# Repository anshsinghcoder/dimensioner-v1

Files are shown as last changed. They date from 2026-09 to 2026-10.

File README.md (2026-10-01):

# dimensioner v1 
MAAP 1 is a automated DIM system that costs 10 times less compared to the current options . 
it is aluminum blasted but u can completely use fibre 3d printing for this . i have removed the wieging scale from research that most users dont need it. 

Overview:
MAAP-1 Utilizes a custom ESP32-based PCB, 3 LiDAR sensors to  instantly calculate the length ,  height and width of any parcel .
Designed for logistics, warehouses . i have included electronics components make sure u add it in your cad library. sorry though not much room for customisation many pins are used , feel free to play around with the scematics if u wish
- it also features a camera system which snaps images along side the dim . how ever please make sure the camera module u use comes with a sd slot or just add a pin. 

Hardware Architecture
1. Custom PCB (KiCad)
The brains of the operation is a custom PCB designed to be attached anywhere in the frame it has a 2 hole enclosure that is also included .

Microcontroller: ESP32-WROOM
Power: 5V input, regulated to 3.3V via AMS1117 for logic.

2. Mechanical Structure
  - T-slot aluminum extrusion holding the overhead LiDAR .
  - Dual forward-facing structural arms housing inward-facing LiDARs 
  - control box housing the custom PCB, screen, buttons, and thermal printer.

Repository Structure

MAAP-1:
- Firmware             # PLEASE CALIBRATE AS PER NEEDS 
- Hardware            # KiCad PCB design files, Schematics, and Gerbers
- Mechanical           # 3D files for the enclosure and arms PLEASE ADD THE PCB ENCLOSURE AND SCREEN WHERE YOU NEED .
- README.md             # Project documentation

Here is the complete Bill of Materials (BOM) to build your own.
IF U WANT AMOUNTS IN DOLLARS PLEASE REFER TO BOM.CSV 

| Component | Qty | Est. Price | Link / Source |
| --- | --- | --- | --- |
| **ESP32 WROOM-32 Dev Board** | 1 | ₹1850 | [Robu.in](https://robu.in/product/nodemcu-esp-32s-esp-32e-wifi-serial-wifi-bluetooth/?utm_source=gemini) |
| **ESP32-CAM Module** | 1 | ₹2499 | [Robu.in](https://robu.in/product/esp32-cam-wifi-module-bluetooth-with-ov2640-camera-module-2mp/?utm_source=gemini) |
| **VL53L0X ToF LiDAR Sensor** | 3 | ₹4500 *(₹1499 each)* | [Robu.in](https://www.google.com/search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) |
| **1.3" I2C OLED Display (White)** | 1 | ₹299 | [Robu.in](https://robu.in/product/1-3-inch-i2c-oled-display-module-4-pin-white/?utm_source=gemini) |
| **Mechanical Switch / Arcade Button** | 1 | ₹150 | Local Electronics Market |
| **5V 3A Power Adapter** | 1 | ₹250 | Local Electronics Market |
| **LED Strip / Ring Light (6000K)** | 1 | ₹150 | Local Electronics Market |
| **Aluminum 2020 V-Slot Extrusions** | 2m | ₹1000 | Local Hardware Supplier |
| **Clear Polycarbonate/Acrylic Sheets** | 1 | ₹900 | Local Laser-Cutting Shop |
| **Custom PCB (Matte Black + ENIG)** | 5 | ₹1850 | [JLCPCB](https://jlcpcb.com?utm_source=gemini) |
| **Hardware Kit (T-Nuts, M4 Bolts, Brackets)** | 1 | ₹350 | Local Hardware Supplier |



* **Total Estimated Build Cost:** **~₹23,500 (approx. $235 USD)**

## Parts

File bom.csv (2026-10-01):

W | PARTS | qty | PRICE | LINKS
 | ESP32 WROOM-32 Dev Board | 1 | 20$ | [Robu.in](https://robu.in/product/nodemcu-esp-32s-esp-32e-wifi-serial-wifi-bluetooth/?utm_source=gemini)
 | ESP32-CAM Module | 1 | 26$ | [Robu.in](https://robu.in/product/esp32-cam-wifi-module-bluetooth-with-ov2640-camera-module-2mp/
 | VL53L0X ToF LiDAR Sensor | 3 | 45$ (15$ EACH) | [Robu.in](https://www.google.com/search
 | I2C OLED Display (White) | 1 | 4$ | Robu.in](https://robu.in/product/1-3-inch-i2c-oled-display-module-4-pin-white/?utm_source=gemini)
 | Mechanical Switch / Arcade Button | 1 | 3$ | https://techtonics.in/product/tactile-push-button-switch-4-pin-6x6x5-pack-of-10/
 | 5V 3A Power Adapter | 1 | 5$ | Local Electronics Market
 | LED Strip / Ring Light (6000K) | 1 | $4 | Local Electronics Market
 | Aluminum 2020 V-Slot Extrusions | 2m | 20$ | Local Hardware Supplier
 | Clear Polycarbonate/Acrylic Sheets | 1 | 10$ | Local Laser-Cutting Shop
 | Custom PCB | 5 | 25$ | [JLCPCB]
 | Hardware Kit (T-Nuts, M4 Bolts, Brackets) | 1 | 4$ | Local Hardware Supplier

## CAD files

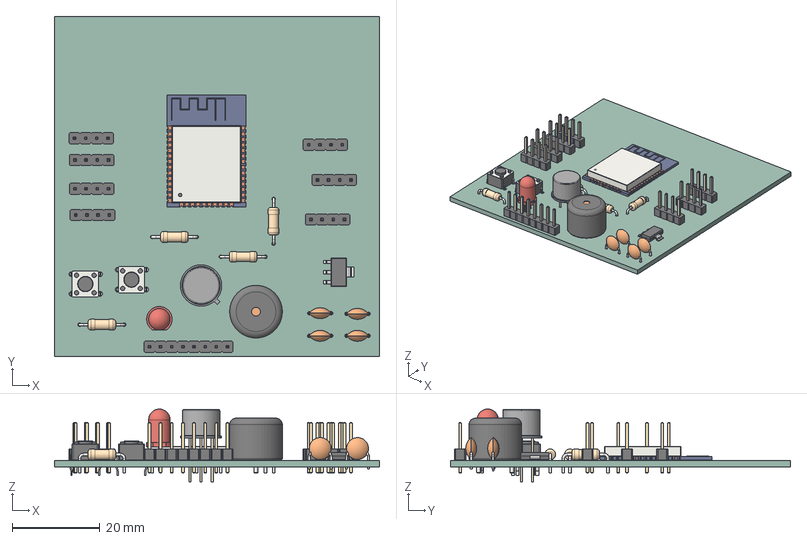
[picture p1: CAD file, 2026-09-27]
hardware/MAAP-1.step
74.0 x 77.5 x 16.6 mm
C_Disc_D50mm_W25mm_P500mm x 4
PinHeader_1x04_P254mm_Vertical x 7
ESP32-WROOM-32
SW_PUSH_6mm x 2
LED_D5.0mm
PinHeader_1x08_P254mm_Vertical
Buzzer_12x95RM76
SOT-223
R_Axial_DIN0207_L63mm_D25mm_P1016mm_Horizontal x 4
TO-39-3
MAA78BE_PCB

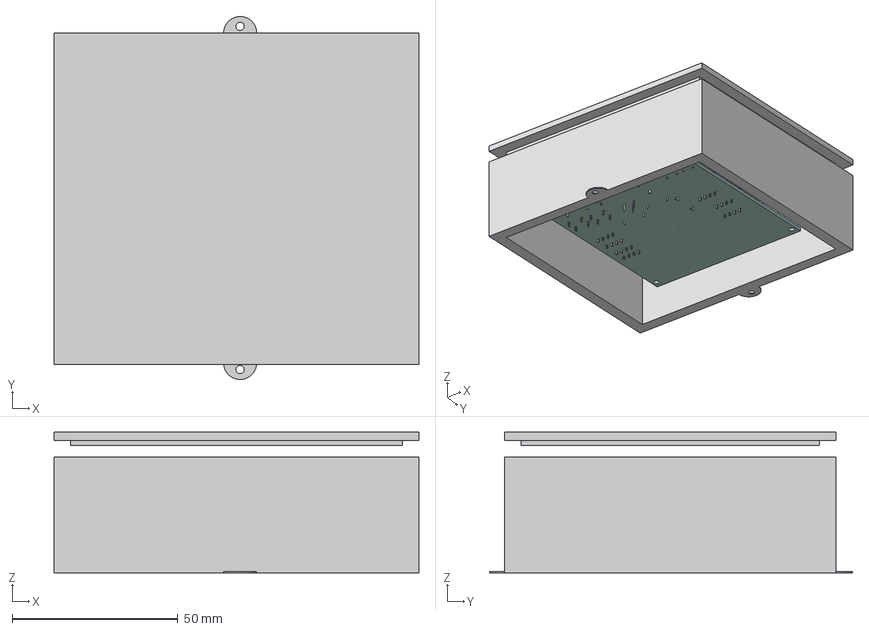
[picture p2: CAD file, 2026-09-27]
mechanical/pcb mounting enclosure.step
110.0 x 109.5 x 42.5 mm

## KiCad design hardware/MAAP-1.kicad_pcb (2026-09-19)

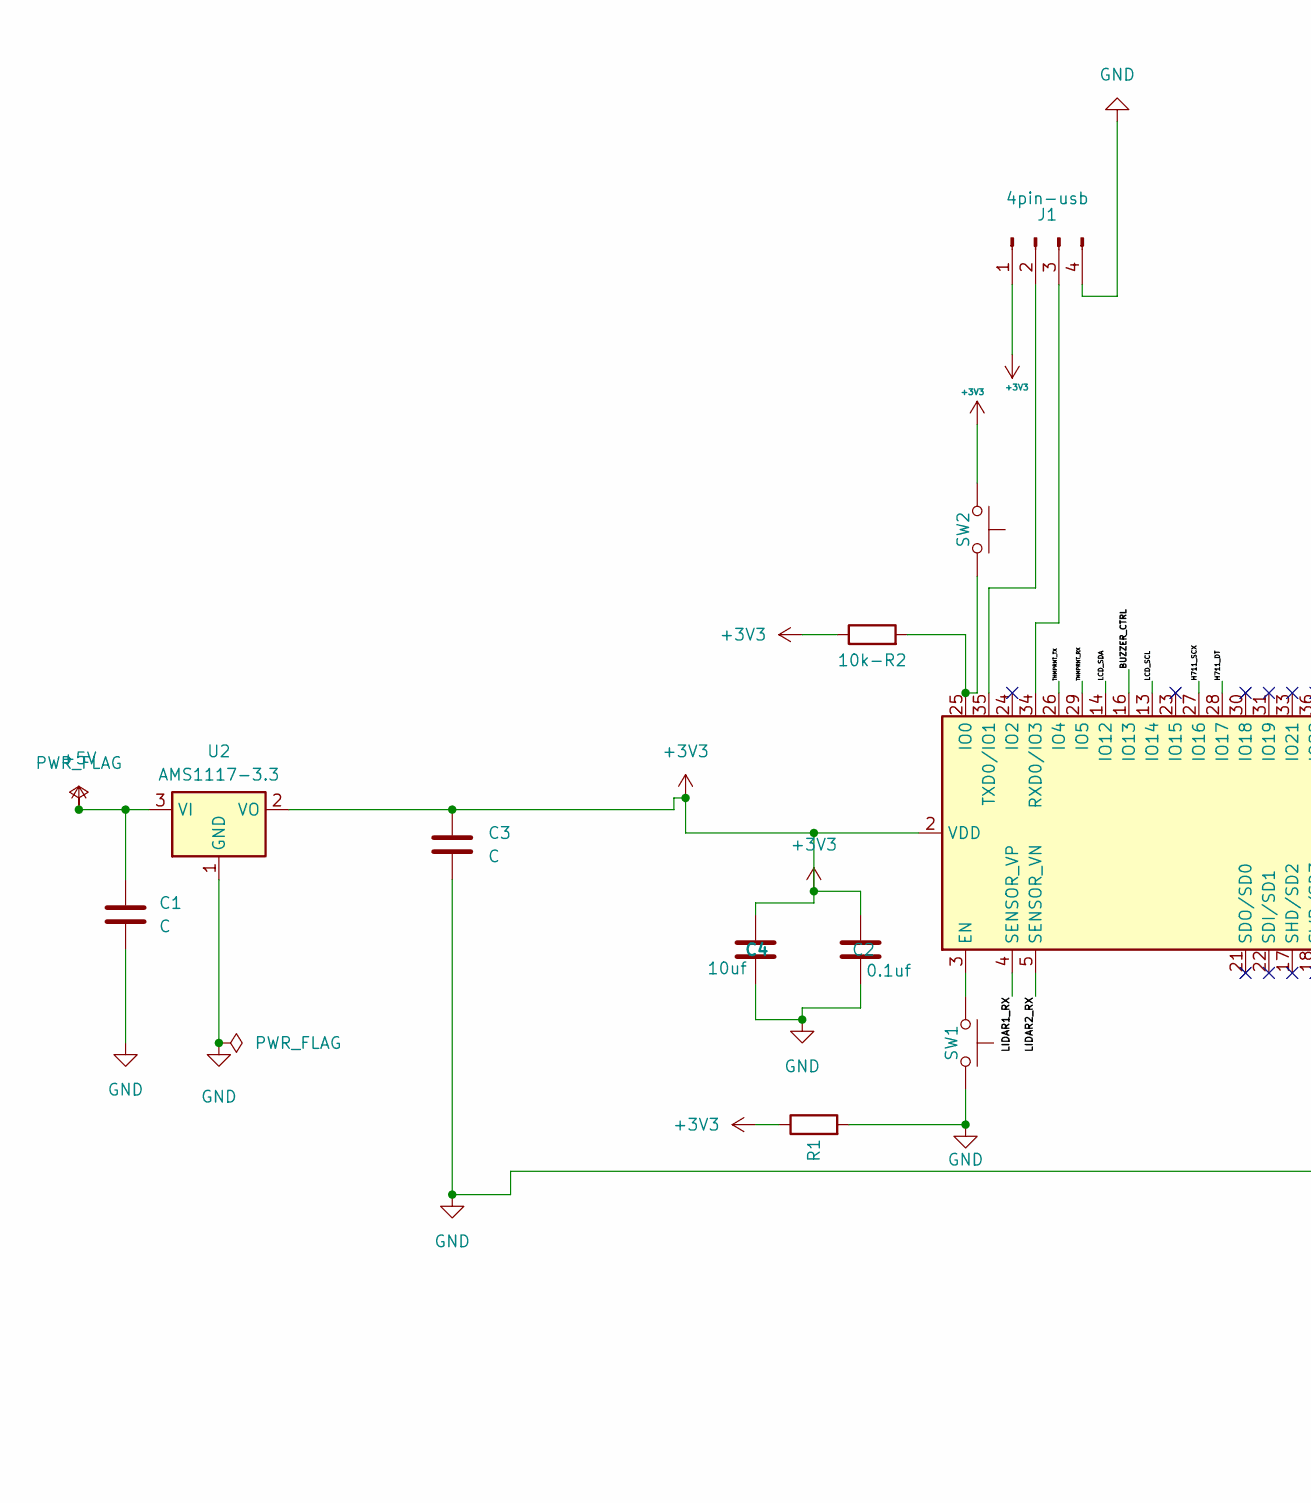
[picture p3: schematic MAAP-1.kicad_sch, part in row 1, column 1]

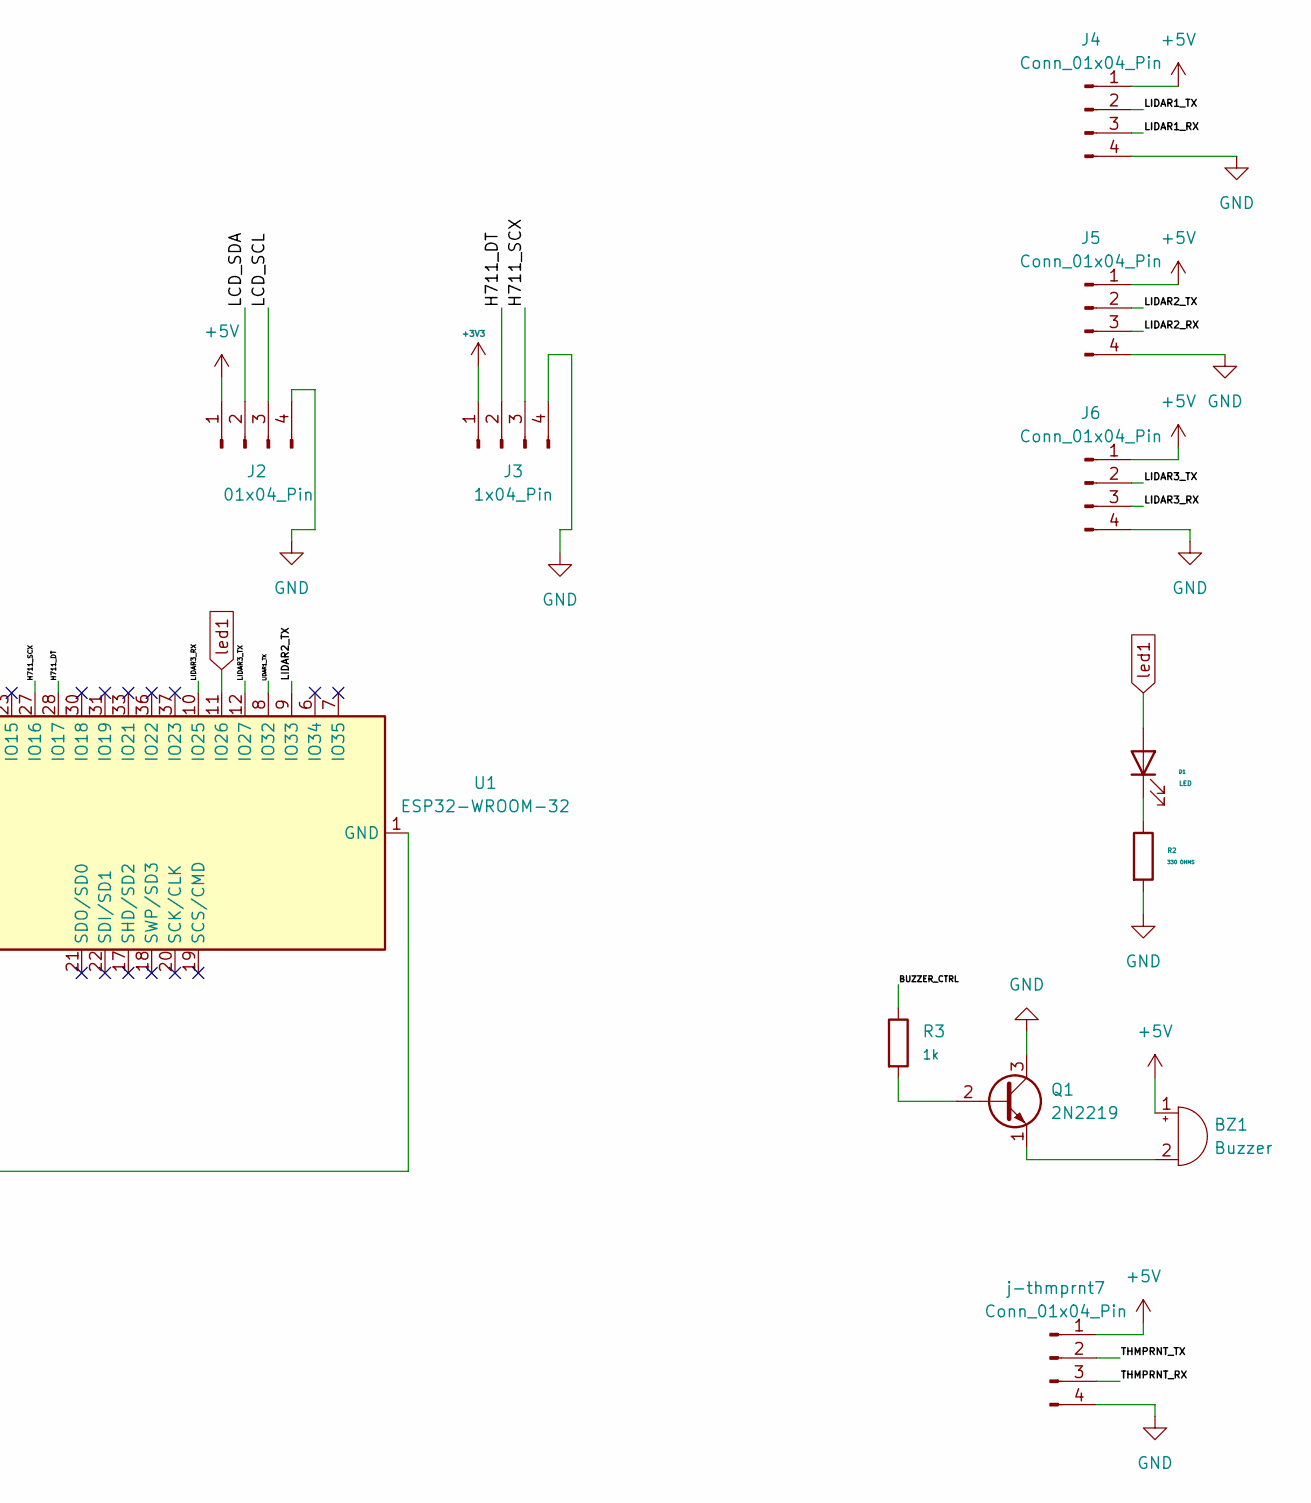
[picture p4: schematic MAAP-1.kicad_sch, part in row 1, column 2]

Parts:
10k-R2: 10k; R_Axial_DIN0207_L6.3mm_D2.5mm_P10.16mm_Horizontal
BZ1: Buzzer; Buzzer_12x9.5RM7.6
C1, C3: C; C_Disc_D5.0mm_W2.5mm_P5.00mm
C2: 0.1uf; C_Disc_D5.0mm_W2.5mm_P5.00mm
C4: 10uf; C_Disc_D5.0mm_W2.5mm_P5.00mm
D1: LED; LED_D5.0mm
J1: 4pin-usb; PinHeader_1x04_P2.54mm_Vertical
J2: 01x04_Pin; PinHeader_1x04_P2.54mm_Vertical
J3: 1x04_Pin; PinHeader_1x04_P2.54mm_Vertical
J4, J5, J6: Conn_01x04_Pin; PinHeader_1x04_P2.54mm_Vertical
Q1: 2N2219; TO-39-3
R1: 10k-r1; R_Axial_DIN0207_L6.3mm_D2.5mm_P10.16mm_Horizontal
R2: 330 OHMS; R_Axial_DIN0207_L6.3mm_D2.5mm_P10.16mm_Horizontal
R3: 1k; R_Axial_DIN0207_L6.3mm_D2.5mm_P10.16mm_Horizontal
SW1, SW2: SW_Push; SW_PUSH_6mm
U1: ESP32-WROOM-32
U2: AMS1117-3.3; SOT-223-3_TabPin2
j-thmprnt7: Conn_01x04_Pin; PinHeader_1x04_P2.54mm_Vertical

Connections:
+3V3: 10k-R2.1, C2.1, C3.1, C4.1, J1.1, J3.1, R1.1, SW2.1, U1.2 (VDD), U2.2 (VO)
+5V: BZ1.1 (+), C1.1, J2.1, J4.1, J5.1, J6.1, U2.3 (VI), j-thmprnt7.1
/BUZZER_CTRL: R3.1, U1.16 (IO13)
/H711_DT: J3.2, U1.28 (IO17)
/H711_SCX: J3.3, U1.27 (IO16)
/LCD_SCL: J2.3, U1.13 (IO14)
/LCD_SDA: J2.2, U1.14 (IO12)
/LIDAR1_RX: J4.3, U1.4 (SENSOR_VP)
/LIDAR1_TX: J4.2, U1.8 (IO32)
/LIDAR2_RX: J5.3, U1.5 (SENSOR_VN)
/LIDAR2_TX: J5.2, U1.9 (IO33)
/LIDAR3_RX: J6.3, U1.10 (IO25)
/LIDAR3_TX: J6.2, U1.12 (IO27)
/THMPRNT_RX: U1.29 (IO5), j-thmprnt7.3
/THMPRNT_TX: U1.26 (IO4), j-thmprnt7.2
GND: C1.2, C2.2, C3.2, C4.2, J1.4, J2.4, J3.4, J4.4, J5.4, J6.4, Q1.3 (C), R1.2, R2.2, SW1.2, U1.1 (GND), U1.15 (GND), U1.38 (GND), U1.39 (GND), U2.1 (GND), j-thmprnt7.4
unnamed: BZ1.2 (-), Q1.1 (E)
unnamed: D1.1 (K), R2.1
unnamed: J1.2, U1.35 (TXD0/IO1)
unnamed: J1.3, U1.34 (RXD0/IO3)
unnamed: Q1.2 (B), R3.2
unnamed: SW1.1, U1.3 (EN)
unnamed: 10k-R2.2, SW2.2, U1.25 (IO0)
led1: D1.2 (A), U1.11 (IO26)

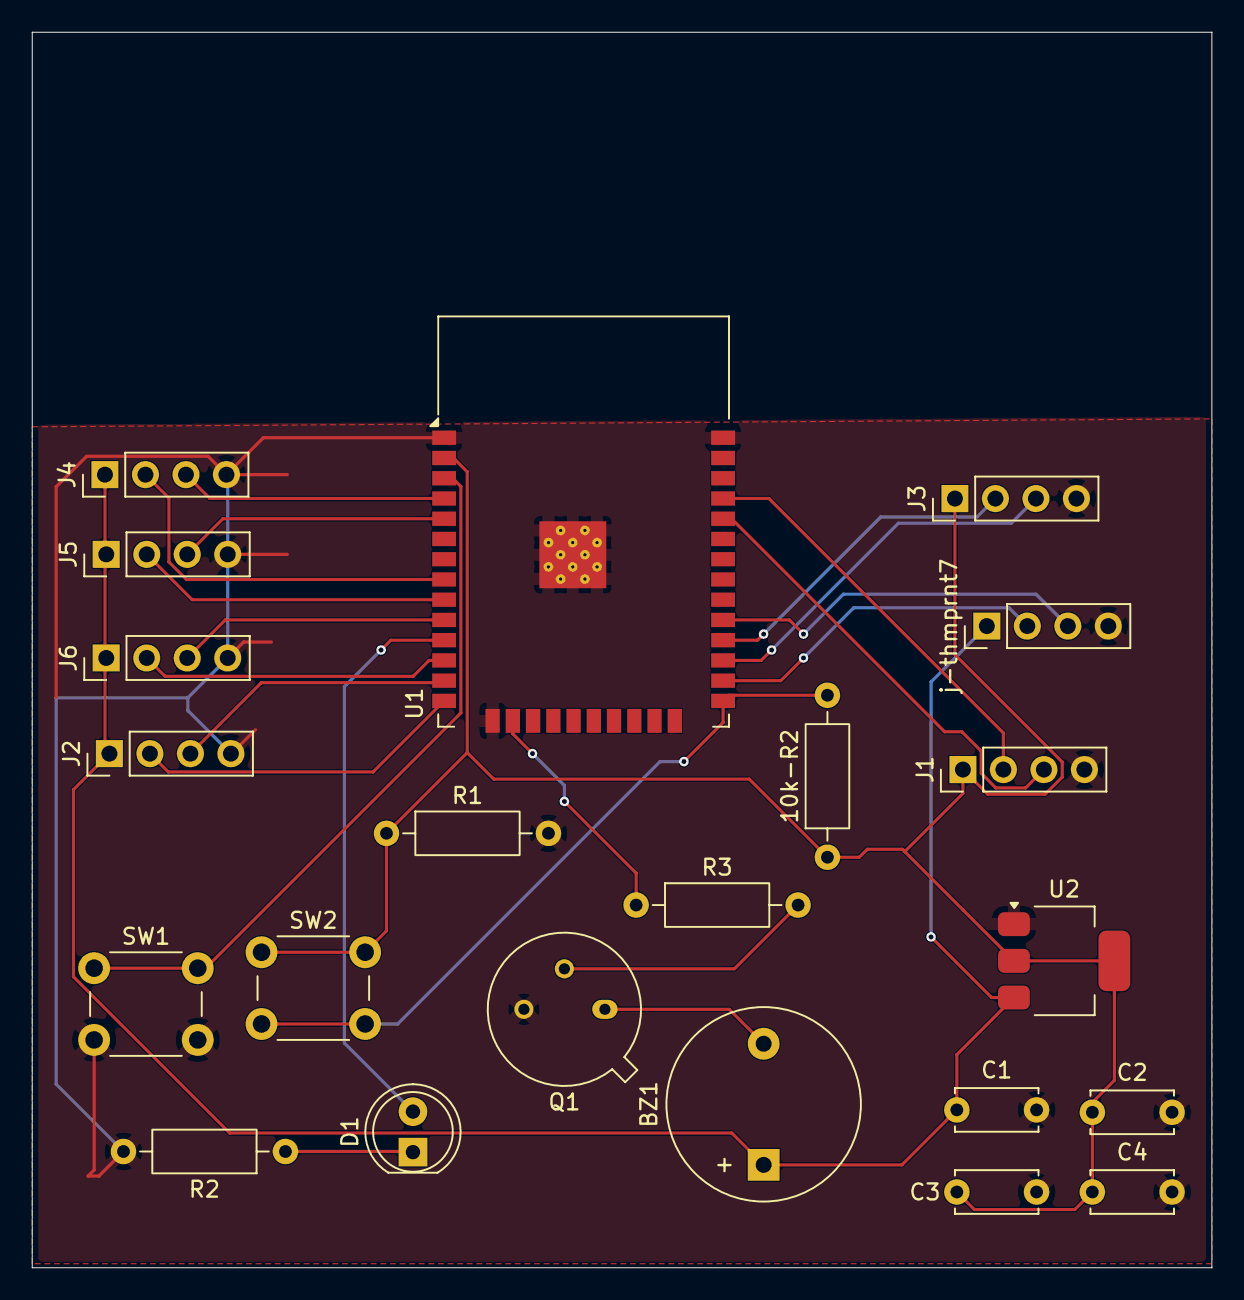
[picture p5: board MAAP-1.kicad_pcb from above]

Board: 2 copper layers, 74.0 x 77.5 mm, 22 parts (0 on the bottom side), 24 nets.

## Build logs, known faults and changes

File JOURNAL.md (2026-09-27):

---
title: "MApv1"
author: "rehann.shaikhh.02"
description: "the dimensioning machine that does not requires you to sell your soul amount of money."
created_at: "2026-09-07"
---

# 2026-09-27: firmware coded 

**Total time spent: 1 hour**

i have written a customisable firmware that user can calibrate as per their base plate and needs . 
it simply uses loops , voids and fuction calls to collect , store , calculate and display LWH and volumetric weight of the item  

# 2026-09-27: pcb enclosure mount 

**Total time spent: 45 minutes**

created a pcb enclosure , imported my pcb , added mounting holes in both the pcb and enclosure . base is not added as i think frame will have a base . lid is given that has a slip and lock bulge that slides perfectly 

# 2026-09-27: cad frame completed 

**Total time spent: 25 minutes**

continuing previous session after recharging my laptop . i created the top lidar sensors unique placement that has a aesthetic arch and a bulge pointing directly at base plate's corner added structures for resting and screen. all thats left is designing a pcb enclosure  

# 2026-09-27: cad session 2 

**Total time spent: 30 mins**

honestly saying in this session i was completely lost , trying to figure out how will wiring work how will screen fit , where to shell , where to join panes , lofting everything . this was completely trial error based session that helped me understand what to do i fixed the sketch and restarted the model , this was better instead of body sweep this extrusion was much better and the shelling was perfect however battery ran out see you soon

# 2026-09-25: cad session 1 

**Total time spent: 35 minutes**

i started to create the cad model and trust me this was frustating as hell , navigating , all thwe controls took me fair share of time to learn which i cant log cuzz its not active development but still this was my try to create the base structure as usual the lapse was not resumed so many times but hey i will still log as much as the lapse 

# 2026-09-25: copper wiring error handling 

**Total time spent: 1 hour 20 minutes**

so what happened was i had simply not taken in fact that i had to position the modules as per the esp module which is fixed in error handling devlog but i came across some tutorials and got to know that u have to create vias for blue wiring . i changed all the wires and created a better layout![Screenshot_2026-09-25_200902.png]

# 2026-09-20: adding a camera module 

**Total time spent: 1 hour**

i forgot to add a camera module pin , basically anytime a product is measured in LWH , its photo gets snapped after it gives a proper info print i had to add a 8 pin to my schematic . rewire it add crazy amount of vias to connect it cuz its 8 pins and i already have 3 sensors etc . but still we are done if u see the 8 pin in the very corner yup thats it !

# 2026-09-19: layout complete 

**Total time spent: 1 hour**

since data base has lost it i'm re-writing this. i had to redo all the wiring as the pcb shifted to the very first session so did the schema . thus i went to schema replaced labels again , updated pcb , again created the layout from start and thanks to previous session recording i had captured all wirings and vias etc . this time i did even cleaner and better. gave my pcb frame , poured copper for grounding , et voila . no errors.

# 2026-09-19: intial layout session 1

**Total time spent: 1 hour**

tried with layout 1 for pcb . had a very hard time wiring copper tracks . in the end i got 71 errors . i could not understood what happened but i was happy that i got the layout but i still had to figure  out a solution to fix these issues . turns out doing this is way hectic than i expected


# 2026-09-19: error handling 

**Total time spent: 40 mins**

this session was more of rewiring everything , because i use trackpad i accidentally over wired almost everything (it took some ai review to understand i wired everything wrong). thus i deleted old wires and made new connections , i forgot to add no connection cross marks thus resolving all errors notice how all the warning arrows are gone yup that was the work ...

# 2026-09-19: schematic session 2 

**Total time spent: 1 hour 45 minutes**

!created usb pin connections , decoupled capacitors , added a thermal priniting module , added lidar sensors , gave power inputs to all it actualy had 111 errors :( . it was quite late in night so left it there . oh and i also added a buzzer and push switch - led for boot check

# 2026-09-19: schematic design 1

**Total time spent: 1 hour 10 minutes**

i created initial schematic loading all core components , wiring basic logical connections , assessing product requirements and adding symbols accordingly. the esp takes 3.3v so to convert the incoming 5v to 3.3v i added a ams module and capacitors. I was not satisfied with this version it needs lot of work

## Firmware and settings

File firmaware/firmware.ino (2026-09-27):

/*  LIBRARIES YOU NEED (Arduino Library Manager):
- "VL53L0X" by Pololu
- "Adafruit SSD1306" + "Adafruit GFX Library"
- ESP32 camera driver (esp_camera.h) 
*/
/* please map the pins and perform LWH calibaration according to your needs , standard is set on 60*60*60 */

VL53L0X sensorL , sensorW , sensorH ; 
Adafruit_SSD1306 display ( SCREEN_WIDTH, SCREEN_HEIGHT, Wire ,-1 );

bool cameraReady = false ; 

void setupCamera() {
    camera_config_t config; 
    config.ledc_channel = LEDC_CHANNEL_0;
    config.ledc_timer = LEDC_TIMER_0; 
       config.pin_d0 = 5;  
       config.pin_d1 = 18;
       config.pin_d2 = 19;
       config.pin_d3 = 21;
       config.pin_d4 =36;
       config.pin_d5 = 39; 
       config.pin_d6 =34;
       config.pin_d7 =35; 
       config.pin_xclx =0;
       config.pin_pclx = 22; 
       config.pin_vsync = 25;
       config.pin_href = 23;
       config.pin_sscb_sda= 26;
       config.pin_sscb_scl = 27;
       config.pin_pwdn = 32;
       config.pin_reset = -1;
       config.pin_freq_hz = 20000000;
       config.pin_format = PIXFORMAT_JPEG;
       config.frame_size = FRAMESIZE_SVGA; 
       config.jpeg_quality = 12;
       config.fb_count = 1 ; 

       if (esp_camera_init(&config) == ESP_OK) {
    cameraReady = true;
  } else {
    Serial.println("Camera init failed continuing without photo capture.");
    cameraReady = false;
  }
}
void resetAllSensors(){
     pinMode(XSHUT_L_PIN, OUTPUT);   
     pinMode(XSHUT_W_PIN, OUTPUT); 
     pinMode(XSHUT_H_PIN, OUTPUT);
    digitalWrite(XSHUT_L_PIN, LOW);
    digitalWrite(XSHUT_W_PIN, LOW);
    digitalWrite(XSHUT_H_PIN, LOW);
    delay(10);
}

bool bringUpSensor(VL53L0X &sensor, int xshutPin, uint8_t newAddr) {
  digitalWrite(xshutPin, HIGH);
  delay(10);
  sensor.setTimeout(500);
  if (!sensor.init()) {
    return false;
  }
  sensor.setAddress(newAddr);
  return true;
}


void setup{
    Serial.begin(1115200);
    delay(200);

    pinMode(BUTTON_PIN, INPUT_PULLUP);
  Wire.begin(I2C_SDA, I2C_SCL);

  resetAllSensors();
bool okL = bringUpSensor(sensorL , XSHUT_L_PIN , ADDR_L );
bool okW = bringUpSensor(sensorW , XSHUT_W_PIN , ADDR_W);
bool okH = bringUpSensor(sensorH , XSHUT_H_PIN , ADDR_H);


if (!okL || !okW || !okH) {
    Serial.println("One or more sensors failed to initialize");
  }
  if (!display.begin(SSD1306_SWITCHCAPVCC, OLED_ADDR)) {
    Serial.println("OLED init failed.");
  }
  display.clearDisplay();
  display.setTextSize(1);
  display.setTextColor(SSD1306_WHITE);
  display.setCursor(0, 0);
  display.println("MAAP-1 Ready");
  display.println("Place box, press button");
  display.display();

  setupCamera();
}

float readDimension( VL53L0X &sensor , float frameSpanMM) {
    int raw = sensor.readRangeSingleMillimeters();
  if (sensor.timeoutOccurred()) {
    return -1; 
  }
  float dimension = frameSpanMM - raw;
  if (dimension < 0) dimension = 0;
  return dimension; 
}

void takeProofPhoto (){
    if (!cameraReady) return ; 
    camera_fb_t *fb = esp_camera_fb_get();
    if(!fb){
        Serial.println("Photo capture failed");
        return; 
    }
    Serial.printf ("Photo capturd : %d bytes\n",
    fb->len); 
    esp_camera_fb_return(fb);}

void showResult(float L_cm, float W_cm, float H_cm, float volWeight) {
  display.clearDisplay();
  display.setCursor(0, 0);
  display.println("MAAP-1 Result");
  display.print("L: "); display.print(L_cm, 1); display.println(" cm");
  display.print("W: "); display.print(W_cm, 1); display.println(" cm");
  display.print("H: "); display.print(H_cm, 1); display.println(" cm");
  display.println("----");
  display.print("Vol Wt: "); display.print(volWeight, 2); display.println(" kg");
  display.display();
}

void runDimensionCycle(){
  display.clearDisplay();
  display.setCursor(0, 0);
  display.println("Measuring...");
  display.display();  

  float L_mm = readDimension(sensorL, FRAME_SPAN_L_MM);
  float W_mm = readDimension(sensorW, FRAME_SPAN_W_MM);
  float H_mm = readDimension(sensorH, FRAME_SPAN_H_MM);

  if (L_mm < 0 || W_mm <  0 || H_mm < 0){
       display.clearDisplay();
       display.setCursor(0, 0);
       display.println("Sensor error.");
       display.println("Try again.");
       display.display();
       return;
 }
   
  float L_cm = L_mm / 10.0;
  float W_cm = W_mm / 10.0;
  float H_cm = H_mm / 10.0;
  
  float volWeight = (L_cm * W_cm * H_cm) / 5000.0;

  serial.printf("L=%,.1fcm W=%.fcm H=%.fcm VolWt =%.2fkg\n", L_cm ,W_cm,H_cm, VolWeight); 
  showResult(L_cm, W_cm, H_cm, volWeight);
  takeProofPhoto();
}

void loop(){
 static bool lastButtonState = HIGH;
 bool currentButtonState = digitalRead(BUTTON_PIN);
 if(lastButtonState == HIGH && currentButtonState == LOW){
     delay(30); 
     if (digitalRead(BUTTON_PIN) == LOW){
        runDimensionCycle();
    }}
  lastButtonState= currentButtonState ; dealy(10);
}

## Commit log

2026-09-19 uploading schema and pcb files
    [MAAP-1.kicad_pcb, MAAP-1.kicad_sch]
2026-09-27 step files uploaded
    [MAAP-1.step, pcb mounting enclosure.step]
2026-09-27 Add Bill of Materials
    Added a complete Bill of Materials (BOM) for building the project, including components, quantities, estimated prices, and links to sources.
2026-10-01 Add note for dollar amounts in BOM
    Added note regarding BOM amounts in dollars.
